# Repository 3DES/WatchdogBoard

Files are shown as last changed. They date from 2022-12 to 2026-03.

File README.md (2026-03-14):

Watchdog PCB, has 8 outputs and 4 inputs. The first output is used as watchdog output and will be switched off if not triggered regularely. Input 0 is the watchdog readback to check if the watchdog can still switch off the output 0 relay.

The relays are powered via USB 5V, what, depending on the used USB cable, can be a bit less sometimes. If you have problems with that change the USB cable or change the layout:
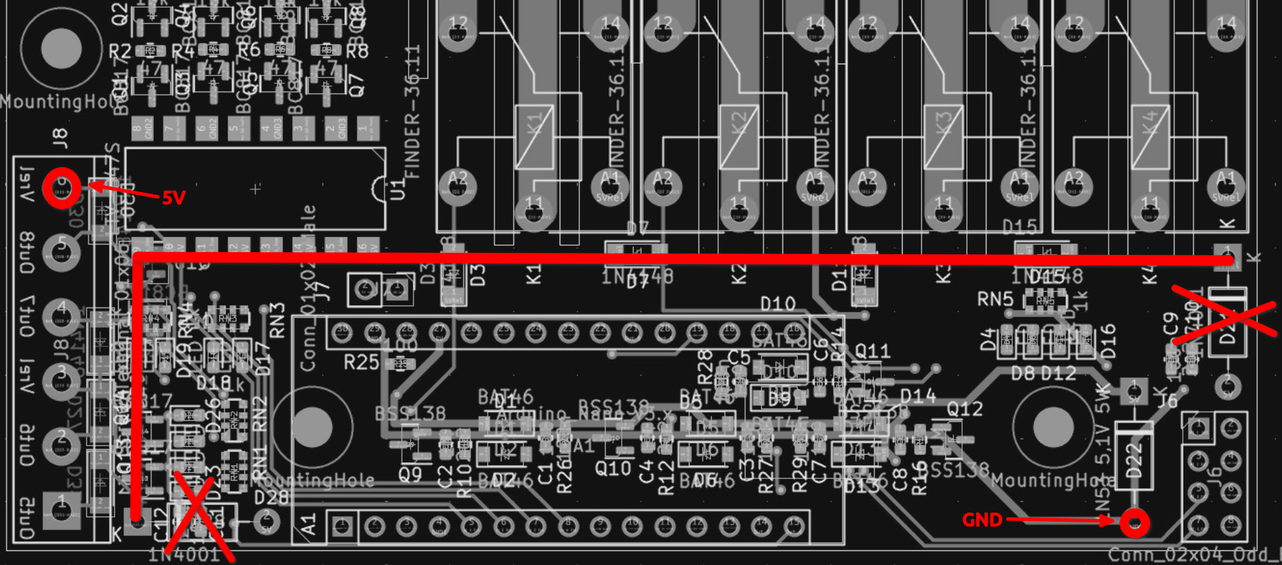
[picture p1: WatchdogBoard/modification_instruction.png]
modification instruction


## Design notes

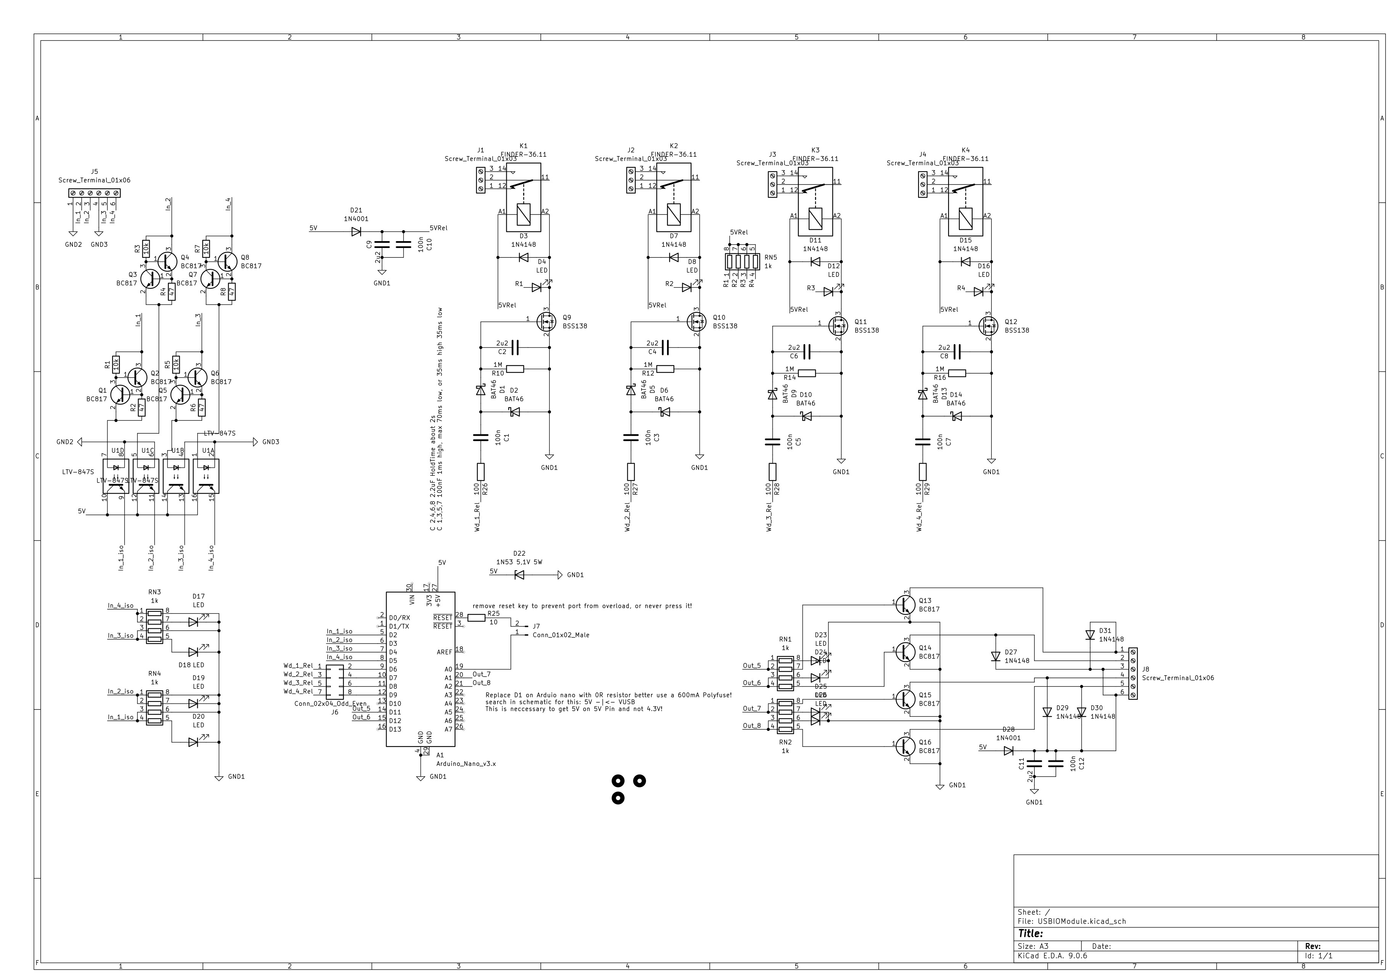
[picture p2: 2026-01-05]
WatchdogBoard/Schematic.jpg

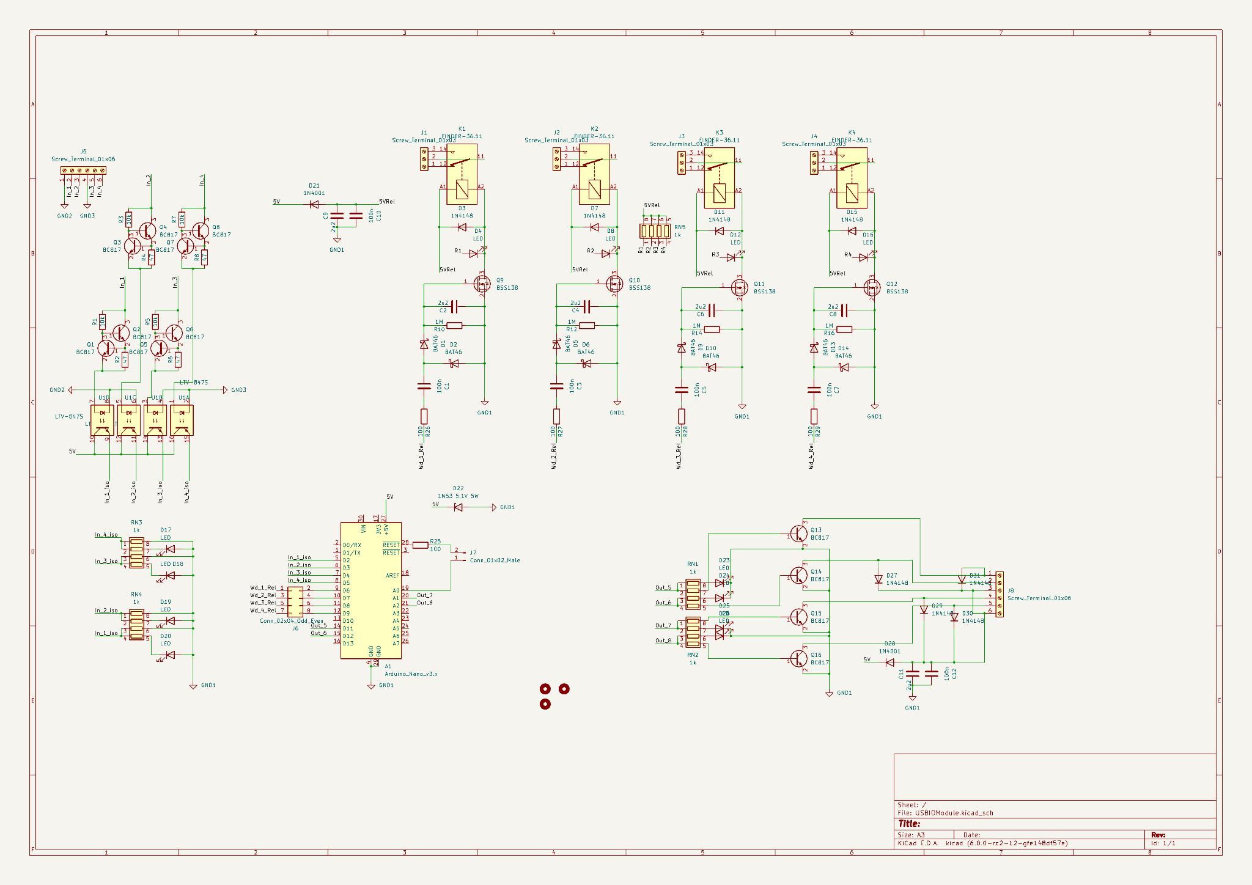
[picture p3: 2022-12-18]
src/schematic.png

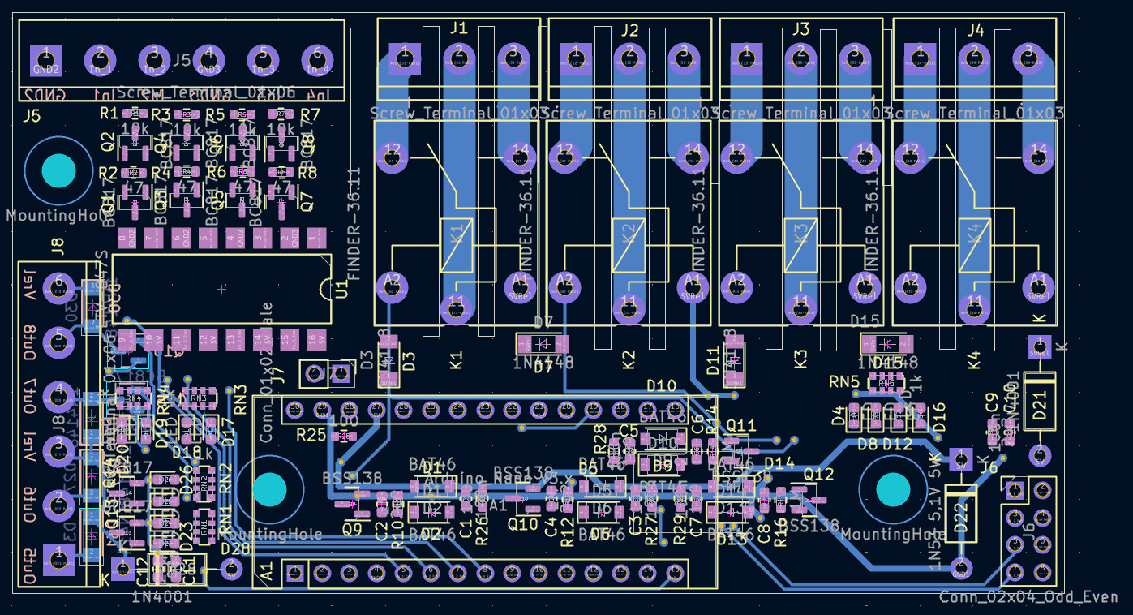
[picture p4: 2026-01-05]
WatchdogBoard/PCB.jpg

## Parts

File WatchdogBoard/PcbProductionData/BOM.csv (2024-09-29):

ID | Bezeichner | Gehäuse | Stückzahl | Bezeichnung | Anbieter und Referenz
1 | J5,J8 | TerminalBlock_bornier-6_P5.08mm | 2 | Screw_Terminal_01x06
2 | RN1,RN5,RN2,RN4,RN3 | R_Array_Convex_4x0612 | 5 | 1k
3 | K4,K2,K1,K3 | Relay_SPDT_Finder_36.11 | 4 | FINDER-36.11
4 | Q9,Q10,Q12,Q11 | SOT-23 | 4 | BSS138
5 | D3,D11,D7,D15,D29,D30,D31,D27 | D_MiniMELF | 8 | 1N4148
6 | R2,R6,R4,R8 | R_0603_1608Metric | 4 | 47
7 | Q5,Q3,Q8,Q14,Q2,Q6,Q7,Q1,Q13,Q4,Q15,Q16 | SOT-23 | 12 | BC817
8 | R1,R7,R3,R5 | R_0603_1608Metric | 4 | 10k
9 | D19,D4,D26,D17,D16,D12,D8,D23,D18,D20,D25,D24 | LED_0603_1608Metric | 12 | LED
10 | U1 | SMDIP-16_W9.53mm | 1 | LTV-847S
11 | R25,R29,R28,R26,R27 | R_0603_1608Metric | 5 | 100
12 | R14,R12,R16,R10 | R_0603_1608Metric | 4 | 1M
13 | J2,J4,J3,J1 | TerminalBlock_bornier-3_P5.08mm | 4 | Screw_Terminal_01x03
14 | H3,H1,H2 | MountingHole_3.2mm_M3 | 3 | MountingHole
15 | A1 | Arduino_Nano | 1 | Arduino_Nano_v3.x
16 | D22 | D_DO-41_SOD81_P10.16mm_Horizontal | 1 | 1N53 5,1V 5W
17 | D14,D1,D2,D9,D13,D6,D5,D10 | D_SOD-123 | 8 | BAT46
18 | D21,D28 | D_DO-41_SOD81_P10.16mm_Horizontal | 2 | 1N4001
19 | C8,C4,C11,C2,C6,C9 | C_0603_1608Metric | 6 | 2u2
20 | C10,C5,C1,C3,C7,C12 | C_0603_1608Metric | 6 | 100n
21 | J6 | PinHeader_2x04_P2.54mm_Vertical | 1 | Conn_02x04_Odd_Even
22 | J7 | PinHeader_1x02_P2.54mm_Vertical | 1 | Conn_01x02_Male

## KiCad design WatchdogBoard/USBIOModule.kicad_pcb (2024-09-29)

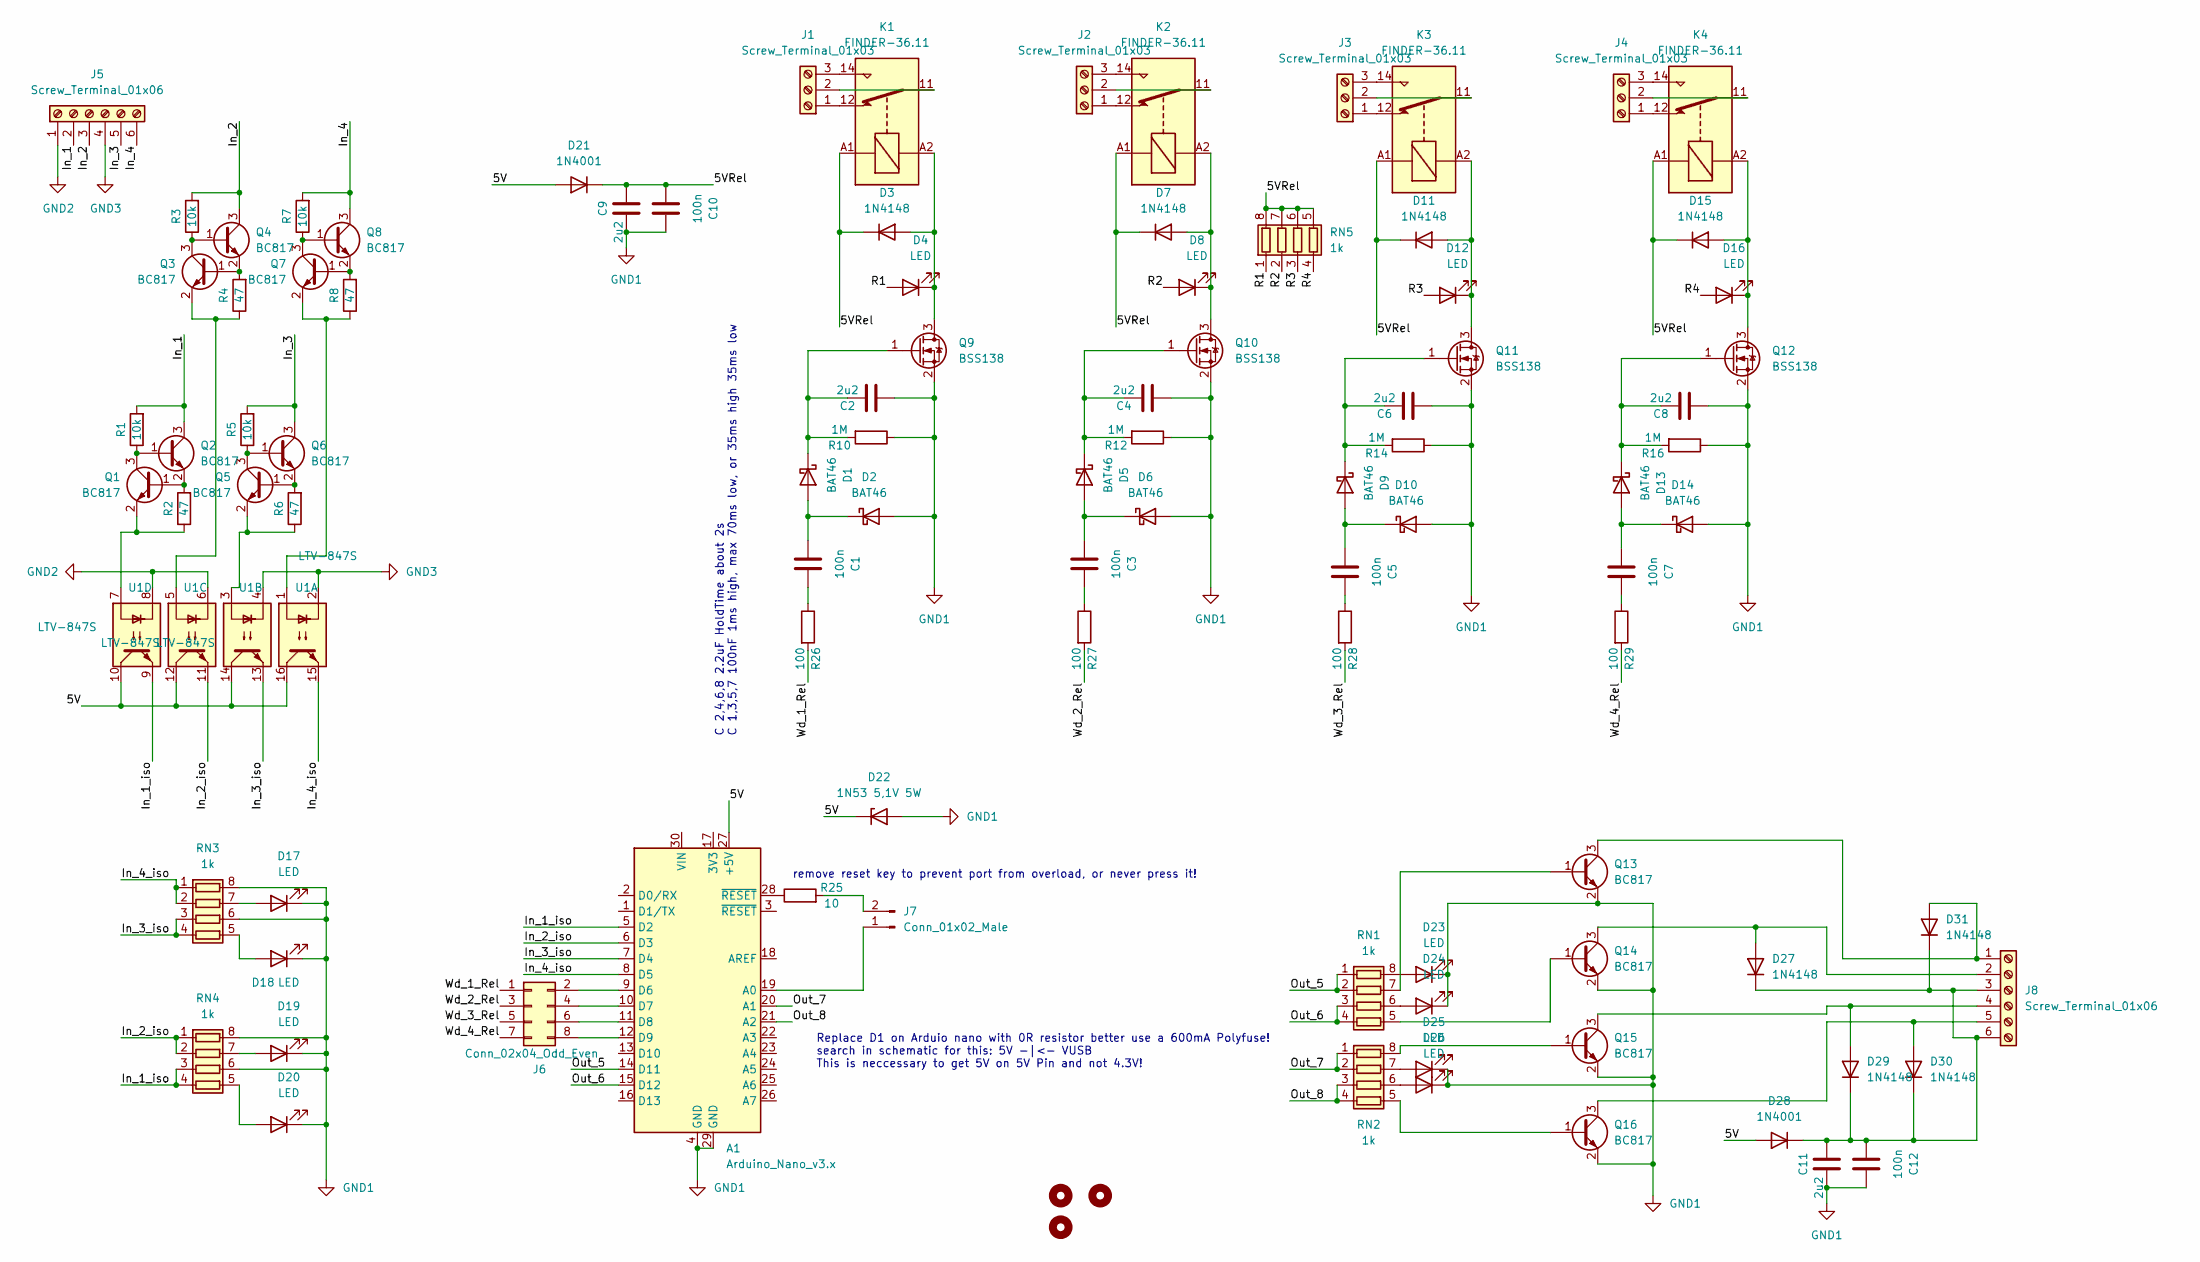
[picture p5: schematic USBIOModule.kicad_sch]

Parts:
A1: Arduino_Nano_v3.x; Arduino_Nano
C1, C3, C5, C7, C10, C12: 100n; C_0603_1608Metric
C2, C4, C6, C8, C9, C11: 2u2; C_0603_1608Metric
D1, D2, D5, D6, D9, D10, D13, D14: BAT46; D_SOD-123
D3, D7, D11, D15, D27, D29, D30, D31: 1N4148; D_MiniMELF
D4, D8, D12, D16, D17, D18, D19, D20, D23, D24, D25, D26: LED; LED_0603_1608Metric
D21, D28: 1N4001; D_DO-41_SOD81_P10.16mm_Horizontal
D22: 1N53 5,1V 5W; D_DO-41_SOD81_P10.16mm_Horizontal
H1, H2, H3: MountingHole; MountingHole_3.2mm_M3
J1, J2, J3, J4: Screw_Terminal_01x03; TerminalBlock_bornier-3_P5.08mm
J5, J8: Screw_Terminal_01x06; TerminalBlock_bornier-6_P5.08mm
J6: Conn_02x04_Odd_Even; PinHeader_2x04_P2.54mm_Vertical
J7: Conn_01x02_Male; PinHeader_1x02_P2.54mm_Vertical
K1, K2, K3, K4: FINDER-36.11; Relay_SPDT_Finder_36.11
Q1, Q2, Q3, Q4, Q5, Q6, Q7, Q8, Q13, Q14, Q15, Q16: BC817; SOT-23
Q9, Q10, Q11, Q12: BSS138; SOT-23
R1, R3, R5, R7: 10k; R_0603_1608Metric
R2, R4, R6, R8: 47; R_0603_1608Metric
R10, R12, R14, R16: 1M; R_0603_1608Metric
R25: 10; R_0603_1608Metric
R26, R27, R28, R29: 100; R_0603_1608Metric
RN1, RN2, RN3, RN4, RN5: 1k; R_Array_Convex_4x0612
U1: LTV-847S; SMDIP-16_W9.53mm

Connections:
/5V: A1.27 (+5V), D21.2 (A), D22.1 (K), D28.2 (A), U1.10, U1.12, U1.14, U1.16
/5VRel: C9.2, C10.1, D3.1 (K), D7.1 (K), D11.1 (K), D15.1 (K), D21.1 (K), K1.A1, K2.A1, K3.A1, K4.A1, RN5.5 (R4.2), RN5.6 (R3.2), RN5.7 (R2.2), RN5.8 (R1.2)
/In_1: J5.2, Q2.3 (C), R1.2
/In_1_iso: A1.5 (D2), RN4.3 (R3.1), RN4.4 (R4.1), U1.9
/In_2: J5.3, Q4.3 (C), R3.2
/In_2_iso: A1.6 (D3), RN4.1 (R1.1), RN4.2 (R2.1), U1.11
/In_3: J5.5, Q6.3 (C), R5.2
/In_3_iso: A1.7 (D4), RN3.3 (R3.1), RN3.4 (R4.1), U1.13
/In_4: J5.6, Q8.3 (C), R7.2
/In_4_iso: A1.8 (D5), RN3.1 (R1.1), RN3.2 (R2.1), U1.15
/Out_5: A1.14 (D11), RN1.1 (R1.1), RN1.2 (R2.1)
/Out_6: A1.15 (D12), RN1.3 (R3.1), RN1.4 (R4.1)
/Out_7: A1.20 (A1), RN2.1 (R1.1), RN2.2 (R2.1)
/Out_8: A1.21 (A2), RN2.3 (R3.1), RN2.4 (R4.1)
/R1: D4.2 (A), RN5.1 (R1.1)
/R2: D8.2 (A), RN5.2 (R2.1)
/R3: D12.2 (A), RN5.3 (R3.1)
/R4: D16.2 (A), RN5.4 (R4.1)
/Wd_1_Rel: J6.1, R26.2
/Wd_2_Rel: J6.3, R27.2
/Wd_3_Rel: J6.5, R28.2
/Wd_4_Rel: J6.7, R29.2
GND1: A1.4 (GND), A1.29 (GND), C2.2, C4.2, C6.2, C8.2, C9.1, C10.2, C11.1, C12.2, D2.2 (A), D6.2 (A), D10.2 (A), D14.2 (A), D17.1 (K), D18.1 (K), D19.1 (K), D20.1 (K), D22.2 (A), D23.1 (K), D24.1 (K), D25.1 (K), D26.1 (K), Q9.2 (S), Q10.2 (S), Q11.2 (S), Q12.2 (S), Q13.2 (E), Q14.2 (E), Q15.2 (E), Q16.2 (E), R10.1, R12.1, R14.1, R16.1, RN3.6 (R3.2), RN3.8 (R1.2), RN4.6 (R3.2), RN4.8 (R1.2)
GND2: J5.1, U1.6, U1.8
GND3: J5.4, U1.2, U1.4
unnamed: A1.9 (D6), J6.2
unnamed: A1.10 (D7), J6.4
unnamed: A1.11 (D8), J6.6
unnamed: A1.12 (D9), J6.8
unnamed: A1.19 (A0), J7.1
unnamed: A1.28 (~RESET), R25.1
unnamed: C1.1, D1.2 (A), D2.1 (K)
unnamed: C1.2, R26.1
unnamed: C2.1, D1.1 (K), Q9.1 (G), R10.2
unnamed: C3.1, D5.2 (A), D6.1 (K)
unnamed: C3.2, R27.1
unnamed: C4.1, D5.1 (K), Q10.1 (G), R12.2
unnamed: C5.1, D9.2 (A), D10.1 (K)
unnamed: C5.2, R28.1
unnamed: C6.1, D9.1 (K), Q11.1 (G), R14.2
unnamed: C7.1, D13.2 (A), D14.1 (K)
unnamed: C7.2, R29.1
unnamed: C8.1, D13.1 (K), Q12.1 (G), R16.2
unnamed: C11.2, C12.1, D27.1 (K), D28.1 (K), D29.1 (K), D30.1 (K), D31.1 (K), J8.3, J8.6
unnamed: D3.2 (A), D4.1 (K), K1.A2, Q9.3 (D)
unnamed: D7.2 (A), D8.1 (K), K2.A2, Q10.3 (D)
unnamed: D11.2 (A), D12.1 (K), K3.A2, Q11.3 (D)
unnamed: D15.2 (A), D16.1 (K), K4.A2, Q12.3 (D)
unnamed: D17.2 (A), RN3.7 (R2.2)
unnamed: D18.2 (A), RN3.5 (R4.2)
unnamed: D19.2 (A), RN4.7 (R2.2)
unnamed: D20.2 (A), RN4.5 (R4.2)
unnamed: D23.2 (A), RN1.8 (R1.2)
unnamed: D24.2 (A), RN1.6 (R3.2)
unnamed: D25.2 (A), RN2.7 (R2.2)
unnamed: D26.2 (A), RN2.6 (R3.2)
unnamed: D27.2 (A), J8.2, Q14.3 (C)
unnamed: D29.2 (A), J8.4, Q15.3 (C)
unnamed: D30.2 (A), J8.5, Q16.3 (C)
unnamed: D31.2 (A), J8.1, Q13.3 (C)
unnamed: J1.1, K1.12
unnamed: J1.2, K1.11
unnamed: J1.3, K1.14
unnamed: J2.1, K2.12
unnamed: J2.2, K2.11
unnamed: J2.3, K2.14
unnamed: J3.1, K3.12
unnamed: J3.2, K3.11
unnamed: J3.3, K3.14
unnamed: J4.1, K4.12
unnamed: J4.2, K4.11
unnamed: J4.3, K4.14
unnamed: J7.2, R25.2
unnamed: Q1.1 (B), Q2.2 (E), R2.2
unnamed: Q1.2 (E), R2.1, U1.7
unnamed: Q1.3 (C), Q2.1 (B), R1.1
unnamed: Q3.1 (B), Q4.2 (E), R4.2
unnamed: Q3.2 (E), R4.1, U1.5
unnamed: Q3.3 (C), Q4.1 (B), R3.1
unnamed: Q5.1 (B), Q6.2 (E), R6.2
unnamed: Q5.2 (E), R6.1, U1.3
unnamed: Q5.3 (C), Q6.1 (B), R5.1
unnamed: Q7.1 (B), Q8.2 (E), R8.2
unnamed: Q7.2 (E), R8.1, U1.1
unnamed: Q7.3 (C), Q8.1 (B), R7.1
unnamed: Q13.1 (B), RN1.7 (R2.2)
unnamed: Q14.1 (B), RN1.5 (R4.2)
unnamed: Q15.1 (B), RN2.8 (R1.2)
unnamed: Q16.1 (B), RN2.5 (R4.2)

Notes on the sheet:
C 2,4,6,8 2.2uF HoldTime about 2s C 1,3,5,7 100nF 1ms high, max 70ms low, or 35ms high 35ms low
Replace D1 on Arduio nano with 0R resistor better use a 600mA Polyfuse! search in schematic for this: 5V -|<- VUSB This is neccessary to get 5V on 5V Pin and not 4.3V!
remove reset key to prevent port from overload, or never press it!

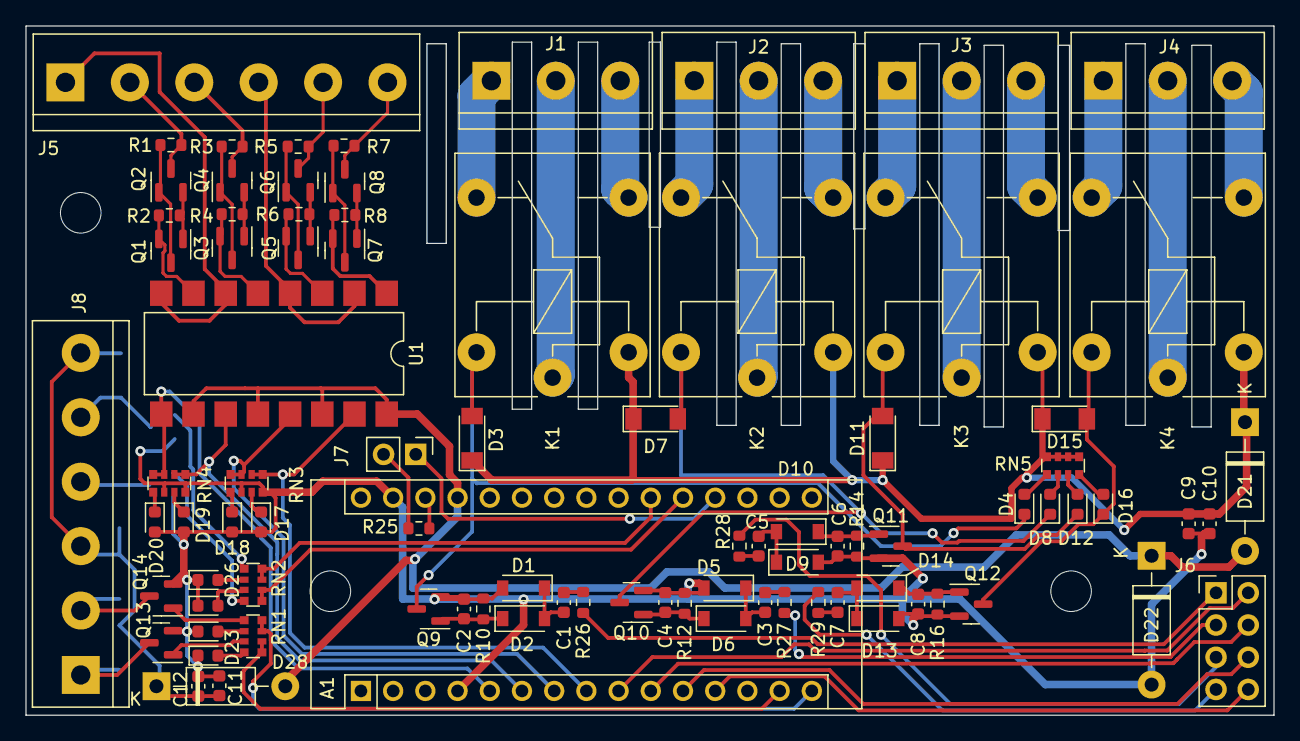
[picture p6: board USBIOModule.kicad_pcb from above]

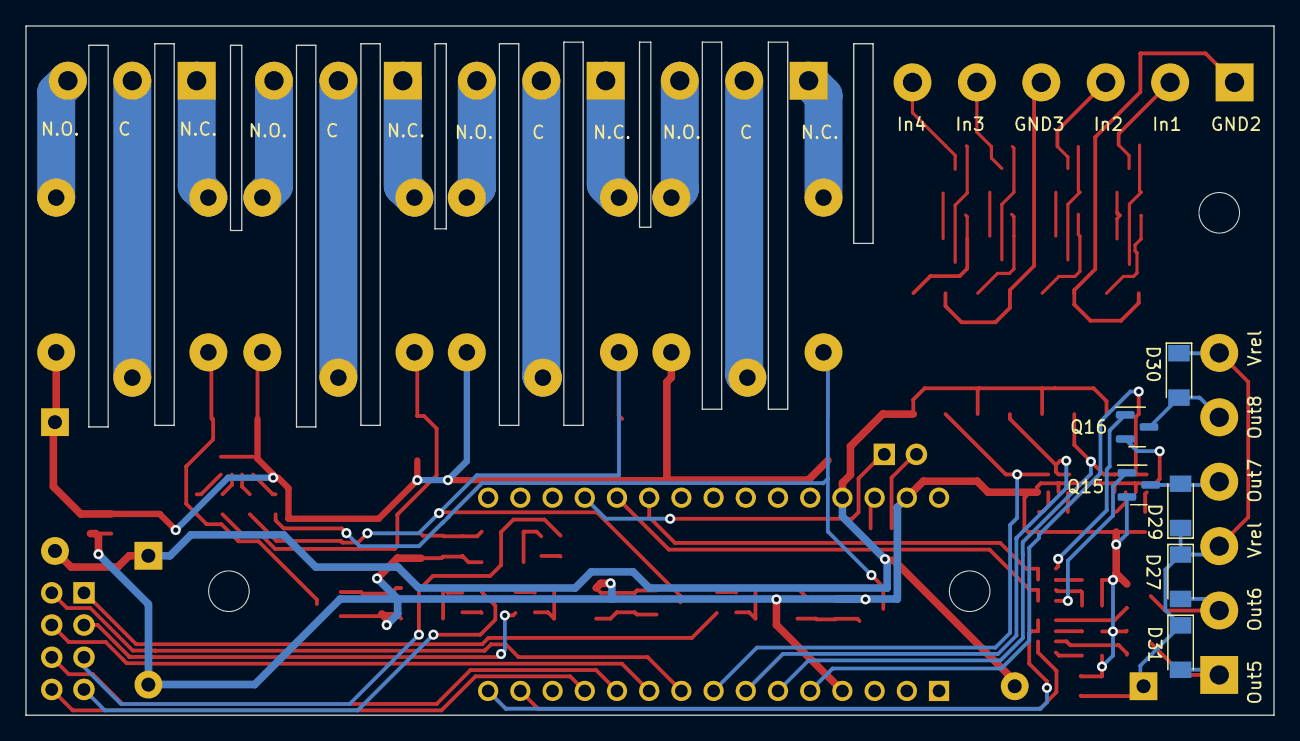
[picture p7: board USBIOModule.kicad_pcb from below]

Board: 2 copper layers, 98.4 x 54.4 mm, 98 parts (6 on the bottom side), 89 nets.

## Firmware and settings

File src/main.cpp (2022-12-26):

#include <Arduino.h>
#include "ioHandler.hpp"
#include "timer.hpp"
#include "messageHandler.hpp"


void setup() {
    Serial.begin(9600);
    debug_setup();
    ioHandler_setup();
    timer_setup();
}


void loop() {
    if (Serial.available() > 0)
    {
        messageHandler_receivedChar(Serial.read());
    }
}

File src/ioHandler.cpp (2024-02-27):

#include <Arduino.h>
#include <pins_arduino.h>
#include <stdint.h>
#include <stdbool.h>
#include "ioHandler.hpp"
#include "timer.hpp"
#include "watchdog.hpp"
#include "debug.hpp"


#if SUPPORTED_OUTPUTS != 7
#error exactly 7 outputs are supported
#endif

#if SUPPORTED_INPUTS != 4
#error exactly 4 inputs are supported
#endif

#define ADDITIONAL_OUTPUTS 1

static bool outputs[eSUPPORTED_OUTPUTS];    // output states,    false per default
static bool inputs[eSUPPORTED_INPUTS];      // input states,     false per default

static bool highCycle = false;              // switch all outputs synchronized, in highCycle phase switch all active outputs ON, in !highCycle phase switch all active outputs OFF

#define WATCHDOG_OUTPUT D6

static const uint8_t inputPorts[eSUPPORTED_INPUTS] = {D2, D3, D4, D5};
static const uint8_t outputPorts[eSUPPORTED_OUTPUTS + ADDITIONAL_OUTPUTS]    = {D7, D8, D9, D11, D12, A1, A2, /* watchdog output... */ WATCHDOG_OUTPUT};        // all output ports including the watchdog output port that has to be the last given one!!!
static const bool    pulsedPorts[eSUPPORTED_OUTPUTS + ADDITIONAL_OUTPUTS]    = {1,  1,  1,  0,   0,   0,  0,  /* watchdog output... */ 1};         // a value > 0 means output has to be pulsed, last value relates to the watchdog port and is ignored (pulsed always)!!! This is not intended to save energy!
static const uint8_t ledPin = D13;
static const uint8_t resetLockPin = A0;         // needs to be switched between ON and hi-Z

enum
{
    eWATCH_DOG_INDEX  = eSUPPORTED_OUTPUTS,         // second last entry in outputPorts is the watchdog port!!!
};

static const uint8_t watchDogPort  = outputPorts[eWATCH_DOG_INDEX];


// set output port to 1 means toggle it every time this method has been called (outputs and watchdog can be handled, the caller has to ensure that the right output is set!)
static void setOutputPort(uint8_t outputNumber)
{
    if (outputNumber < sizeof(outputPorts))
    {
        // toggle watchdog port and pulsed port but switch ON not-pulsed port
        if (highCycle || (!pulsedPorts[outputNumber] && (outputNumber != eWATCH_DOG_INDEX)))
        {
            digitalWrite(outputPorts[outputNumber], HIGH);
        }
        else
        {
            digitalWrite(outputPorts[outputNumber], LOW);
        }
    }
}


// switch output port off (outputs and watchdog can be handled, the caller has to ensure that the right output is cleared!)
static void clearOutputPort(uint8_t outputNumber)
{
    if (outputNumber < sizeof(outputPorts))
    {
        digitalWrite(outputPorts[outputNumber], LOW);
    }
}


// read input pin and return current state as boolean
static bool getInputPort(uint8_t inputNumber)
{
    bool value = false;
    if (inputNumber < eSUPPORTED_INPUTS)
    {
        value = (digitalRead(inputPorts[inputNumber]) != 0);
    }

    return value;
}


// set watchdog port to 1 (OK)
static inline void setWatchdogPort(void)
{
    setOutputPort(eWATCH_DOG_INDEX);
}


// set watchdog port to 0 (ERROR)
static inline void clearWatchdogPort(void)
{
    clearOutputPort(eWATCH_DOG_INDEX);
}


// lock reset pin to prevent reset during UART connection
static inline void lockResetPort(void)
{
    // set pin to HIGH
    digitalWrite(resetLockPin, HIGH);       // ensure it's set to HIGH as soon as it will be configured as output (since it's currently an input the pull-up will be switched now, what is OK)
    pinMode(resetLockPin, OUTPUT);
}


// unlock reset pin, reset during UART connection is possible and e.g. new firmware can be installed
static inline void unlockResetPort(void)
{
    // set pin to hi-Z
    pinMode(resetLockPin, INPUT);           // meanwhile set it to hi-Z
    digitalWrite(resetLockPin, LOW);        // disable pullup because "HIGH" in input mode means pullup is enabled
}


// setup used io ports
void ioHandler_setup(void)
{
    for (uint8_t index = 0; index < sizeof(outputPorts); index++)
    {
        pinMode(outputPorts[index], OUTPUT);
    }

    for (uint8_t index = 0; index < sizeof(inputPorts); index++)
    {
        pinMode(inputPorts[index], INPUT);
    }

    // arduino nano LED used for diagnosis
    pinMode(ledPin, OUTPUT);
    digitalWrite(ledPin, HIGH);

    // setup reset lock pin (default behavior, so it's not necessary)
    //digitalWrite(resetLockPin, LOW);        // ensure pullup is disabled
    //pinMode(resetLockPin, INPUT);           // meanwhile set it to hi-Z
}


// set output state
void ioHandler_setOutput(uint16_t index, uint8_t value)
{
    if (index < eSUPPORTED_OUTPUTS)
    {
        outputs[index] = (value != 0);
    }
}


// get output state
bool ioHandler_getOutput(uint16_t index)
{
    bool result = false;
    if (index < eSUPPORTED_OUTPUTS)
    {
        result = outputs[index];
    }
    return result;
}


// get input state
bool ioHandler_getInput(uint16_t index)
{
    bool result = false;
    if (index < eSUPPORTED_INPUTS)
    {
        result = inputs[index];
    }
    return result;
}


// just toggle the led on ledPin
static void ledToggle(void)
{
    if (digitalRead(ledPin))
    {
        // LED was ON so switch it OFF now
        digitalWrite(ledPin, LOW);
    }
    else
    {
        // LED was OFF so switch it ON now
        digitalWrite(ledPin, HIGH);
    }
}


// set LED mode and toggle LED if necessary
static inline void handleLed(void)
{
    // supported blink modes
    enum
    {
        eLED_TOGGLE_SLOW = 2000 / eTICK_TIME,
        eLED_TOGGLE_FAST =  100 / eTICK_TIME,
    };
    static uint16_t ledToggleCounter = 0;

    // when counter reaches zero decide what's to do now
    if (!ledToggleCounter)
    {
        switch (watchdog_getState())
        {
            //case eWATCHDOG_STATE_INIT:
            // led is switched ON in setup, so no further action is necessary here
            //    break;

            case eWATCHDOG_STATE_OK:
                // toggle led and set slow blink mode
                ledToggle();
                ledToggleCounter = eLED_TOGGLE_SLOW;
                break;

            case eWATCHDOG_STATE_ERROR:
                // toggle led and set fast blink mode
                ledToggle();
                ledToggleCounter = eLED_TOGGLE_FAST;
                break;
        }
    }
    else
    {
        // counter hasn't reached zero yet
        ledToggleCounter--;
    }
}
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

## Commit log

2022-12-18 watchdog is working, relays are working, inputs are readable
2022-12-26 debug improved, reset lock added, tick time calculation improved, refactored
    [ioHandler.cpp, ioHandler.hpp, messageHandler.cpp]
2022-12-26 all outputs are switched OFF in error case, outputs switched synchronized, arduino LED shows watchdog state
    [ioHandler.cpp]
2022-12-26 refactored, setup calls fixed, reset lock fixed
    [ioHandler.cpp, ioHandler.hpp, main.cpp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]
2023-04-02 single step CRC fixed, new command V added, request and response are no longer identical
    [ioHandler.cpp, ioHandler.hpp, messageHandler.cpp]
2023-04-11 self test simplified and fixed by monitoring expected state for several milliseconds now
    [ioHandler.cpp, messageHandler.cpp]
2023-04-20 wrong error number fixed, little refactored, calculated CRC is sent back in NACK message now to simplify testing
    [messageHandler.cpp]
2023-06-09 outputs switched OFF in case of watchdog error, lock release should work
    [ioHandler.cpp]
2024-09-29 Add watchdog board schematic
    [BOM.csv, USBIOModule.kicad_pcb, USBIOModule.kicad_sch]
2026-01-05 added PCB and schematic as jpg for easier accessability
2026-03-14 png added that shows how to solve 5V problem with USB power supply
